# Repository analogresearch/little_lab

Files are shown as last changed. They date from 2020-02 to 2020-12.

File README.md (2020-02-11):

# LITTLE████_LAB

DC IN: 6..28 V 

MIDI noch noch nicht implementiert.

MIDI channel und Programm werden über Codierschalter gewählt.
MIDI: Ausnahme Schalter 0 = MIDI channel 16!

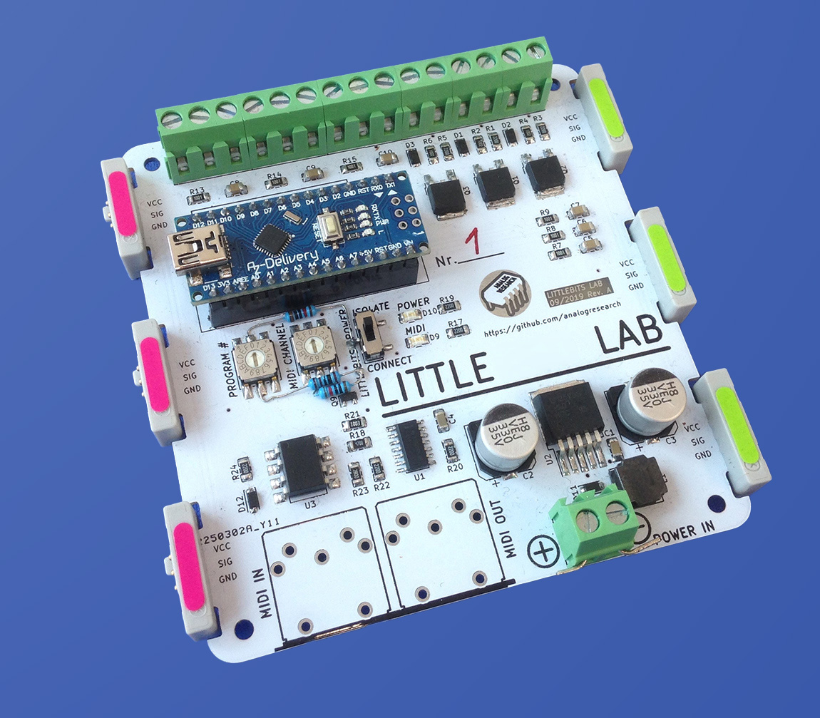
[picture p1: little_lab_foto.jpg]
ein Bild ein Foto


Rev.B: Pullups für Coderschalter
Rev.C: Pulldowns für inputs, debugging pads.

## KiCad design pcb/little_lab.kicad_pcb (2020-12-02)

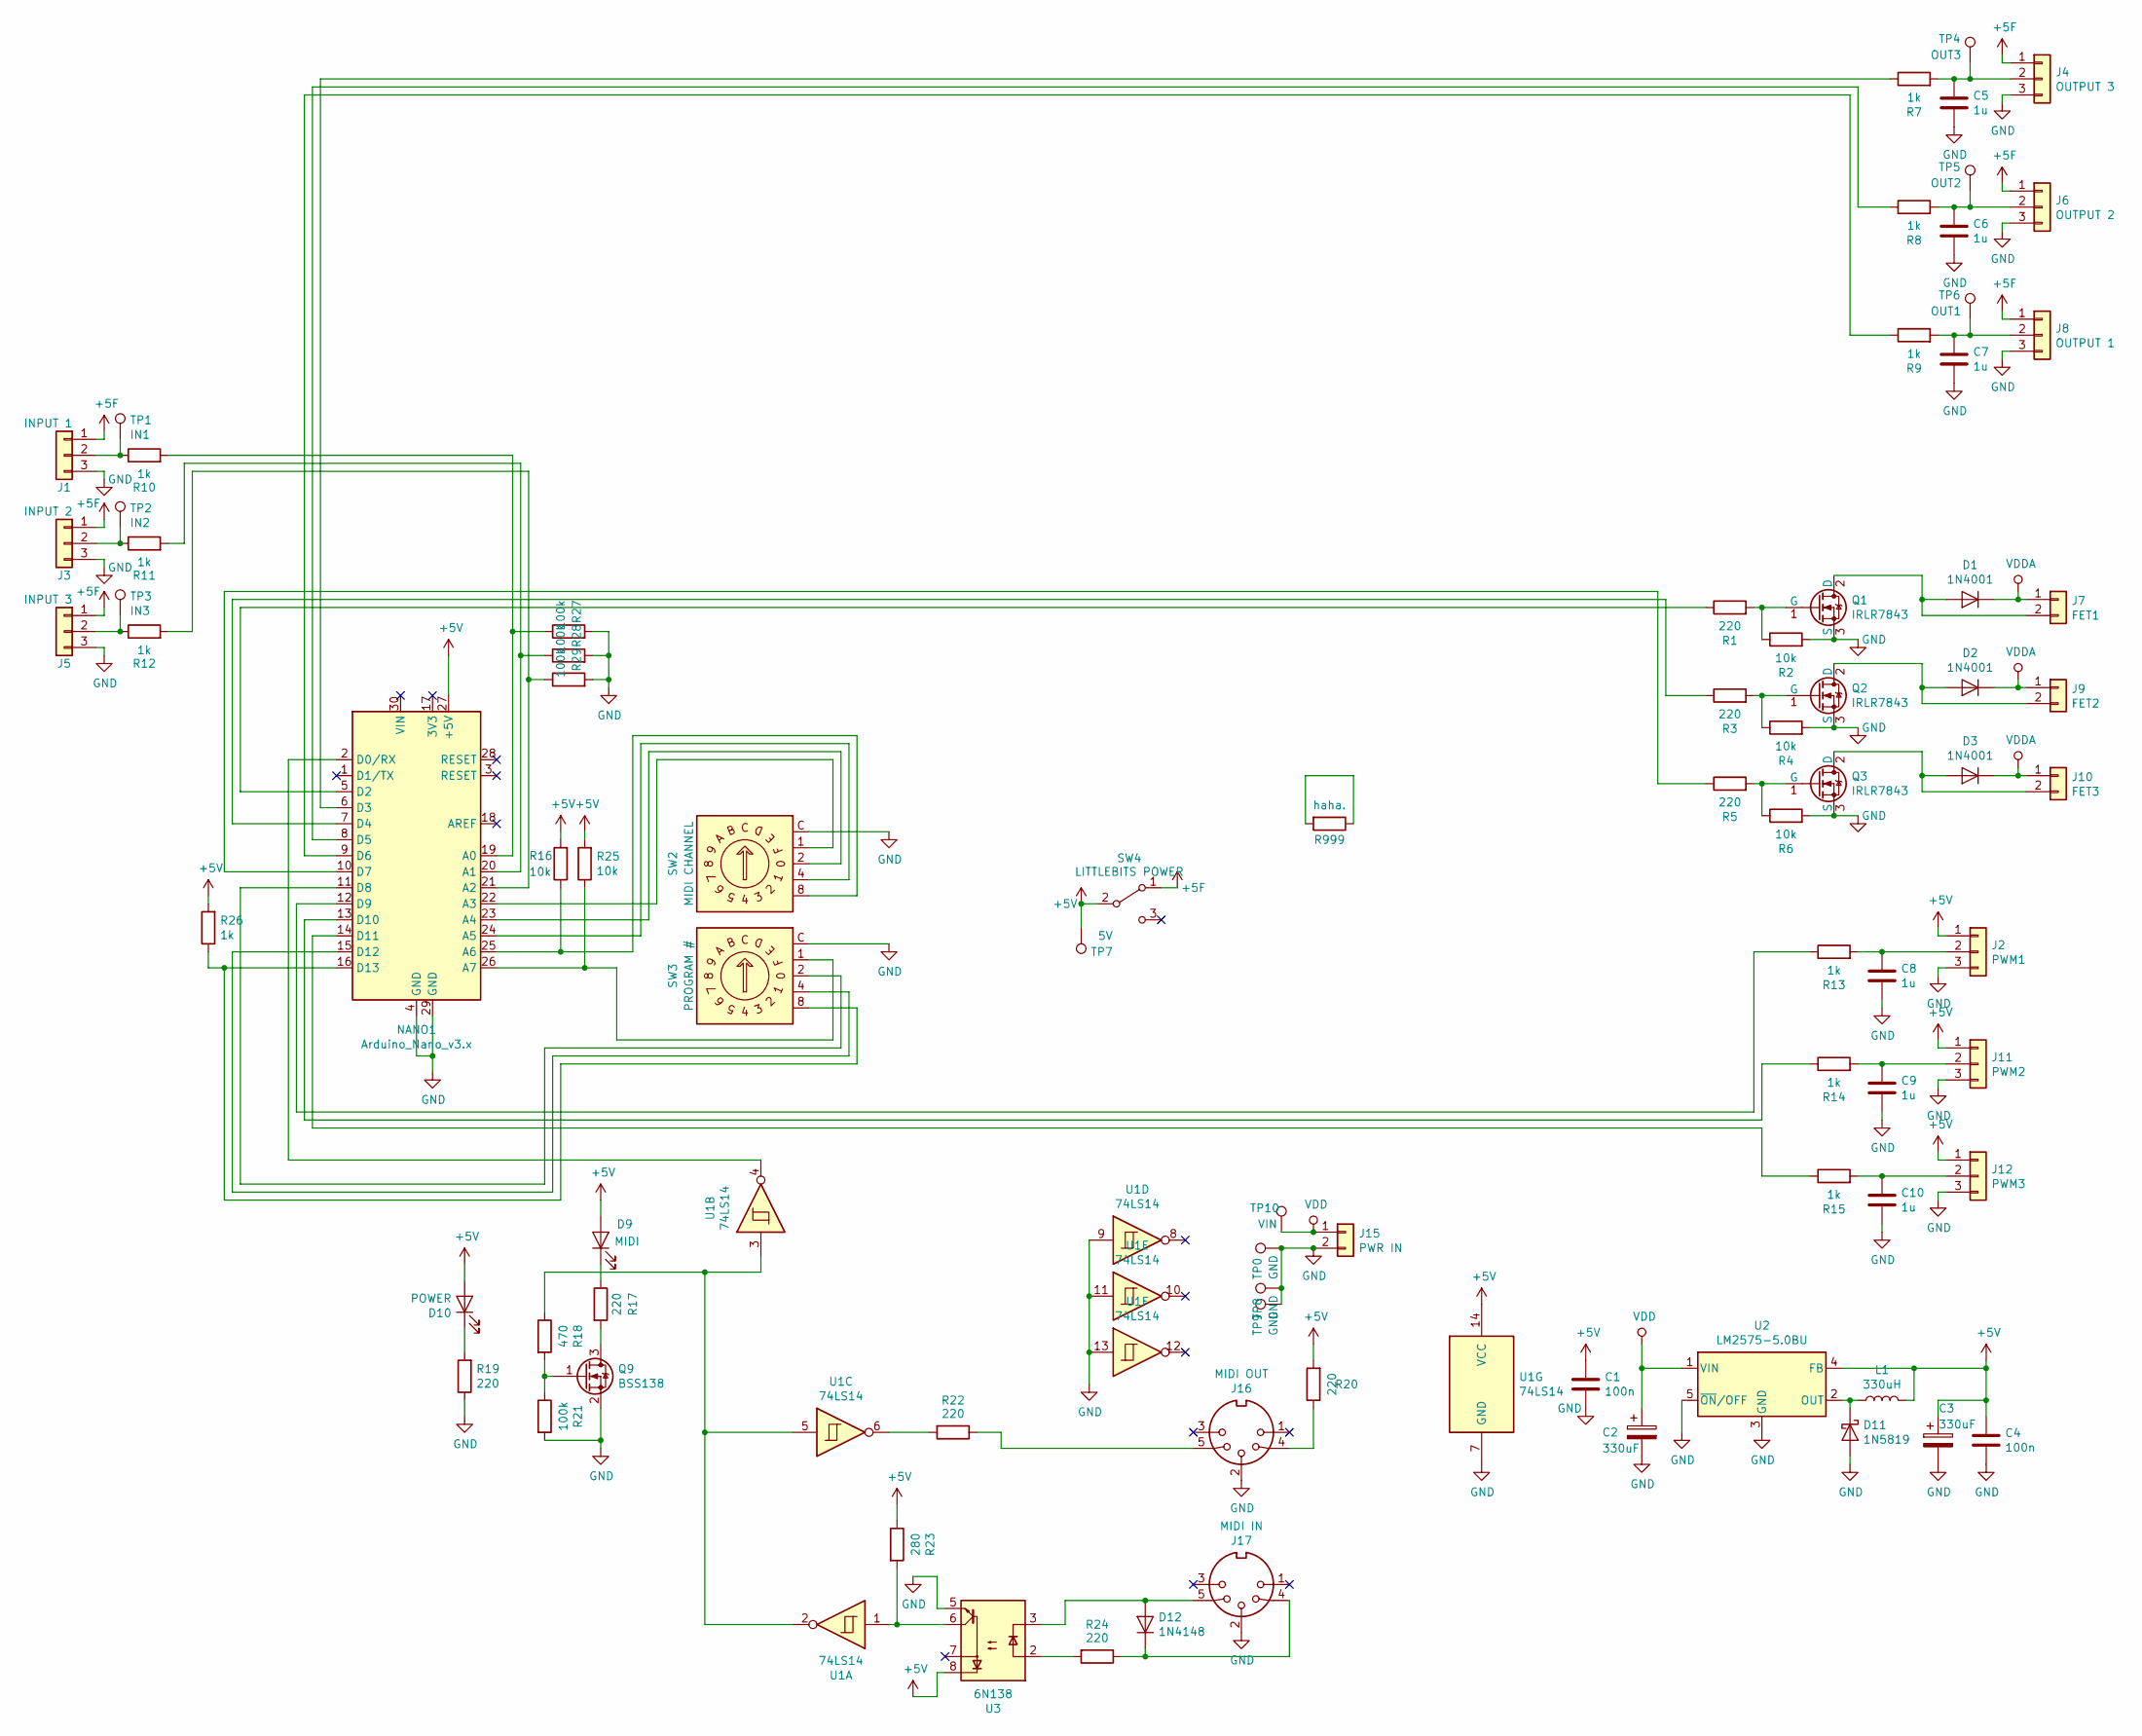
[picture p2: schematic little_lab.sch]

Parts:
C1, C4: 100n; C_1206_3216Metric_Pad1.42x1.75mm_HandSolder
C2, C3: 330uF; CP_Elec_10x10
C5, C6, C7, C8, C9, C10: 1u; C_1206_3216Metric_Pad1.42x1.75mm_HandSolder
D1, D2, D3: 1N4001; D_SOD-123F
D9: MIDI; LED_1206_3216Metric_Pad1.42x1.75mm_HandSolder
D10: POWER; LED_1206_3216Metric_Pad1.42x1.75mm_HandSolder
D11: 1N5819; D_SOD-123
D12: 1N4148; D_SOD-123
J1: INPUT 1; bitsnaps_input
J2: PWM1; EK508V-03P
J3: INPUT 2; bitsnaps_input
J4: OUTPUT 3; bitsnaps_output
J5: INPUT 3; bitsnaps_input
J6: OUTPUT 2; bitsnaps_output
J7: FET1; EK508V-02P
J8: OUTPUT 1; bitsnaps_output
J9: FET2; EK508V-02P
J10: FET3; EK508V-02P
J11: PWM2; EK508V-03P
J12: PWM3; EK508V-03P
J15: PWR IN; EK508V-02P
J16: MIDI OUT; MIDI_DIN5
J17: MIDI IN; MIDI_DIN5
L1: 330uH; L_7.3x7.3_Handsoldering
NANO1: Arduino_Nano_v3.x; Arduino_Nano
Q1, Q2, Q3: IRLR7843; TO-252-2
Q9: BSS138; SOT-23
R1, R3, R5, R17, R19, R20, R22, R24: 220; R_1206_3216Metric_Pad1.42x1.75mm_HandSolder
R2, R4, R6, R16, R25: 10k; R_1206_3216Metric_Pad1.42x1.75mm_HandSolder
R7, R8, R9, R10, R11, R12, R13, R14, R15, R26: 1k; R_1206_3216Metric_Pad1.42x1.75mm_HandSolder
R18: 470; R_1206_3216Metric_Pad1.42x1.75mm_HandSolder
R21, R27, R28, R29: 100k; R_1206_3216Metric_Pad1.42x1.75mm_HandSolder
R23: 280; R_1206_3216Metric_Pad1.42x1.75mm_HandSolder
R999: haha.; R_1206_3216Metric_Pad1.42x1.75mm_HandSolder
SW2: MIDI CHANNEL; SA-7050B
SW3: PROGRAM #; SA-7050B
SW4: LITTLEBITS POWER; K3-1235S-K1
TP0: GND; TestPoint_THTPad_D2.0mm_Drill1.0mm
TP1: IN1; TestPoint_THTPad_D2.0mm_Drill1.0mm
TP2: IN2; TestPoint_THTPad_D2.0mm_Drill1.0mm
TP3: IN3; TestPoint_THTPad_D2.0mm_Drill1.0mm
TP4: OUT3; TestPoint_THTPad_D2.0mm_Drill1.0mm
TP5: OUT2; TestPoint_THTPad_D2.0mm_Drill1.0mm
TP6: OUT1; TestPoint_THTPad_D2.0mm_Drill1.0mm
TP7: 5V; TestPoint_THTPad_D2.0mm_Drill1.0mm
TP8, TP9: GND; TestPoint_Pad_4.0x4.0mm
TP10: VIN; TestPoint_THTPad_D2.0mm_Drill1.0mm
U1: 74LS14; SOIC-14_3.9x8.7mm_P1.27mm
U2: LM2575-5.0BU; TO-263-5_TabPin3
U3: 6N138; SMDIP-8_W9.53mm

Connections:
+5F: J1.1, J3.1, J4.1, J5.1, J6.1, J8.1, SW4.1 (A)
+5V: C1.1, C3.1, C4.1, D9.2 (A), D10.2 (A), J2.1, J11.1, J12.1, L1.2, NANO1.27 (+5V), R16.2, R20.2, R23.1, R25.2, R26.2, SW4.2 (B), TP7.1, U1.14 (VCC), U2.4 (FB), U3.8
GND: C1.2, C2.2, C3.2, C4.2, C5.2, C6.2, C7.2, C8.2, C9.2, C10.2, D11.2 (A), J1.3, J2.3, J3.3, J4.3, J5.3, J6.3, J8.3, J11.3, J12.3, J15.2, J16.2, J17.2, NANO1.4 (GND), NANO1.29 (GND), Q1.3 (S), Q2.3 (S), Q3.3 (S), Q9.2 (S), R2.2, R4.2, R6.2, R19.1, R21.2, R27.2, R28.2, R29.2, SW2.C, SW3.C, TP0.1, TP8.1, TP9.1, U1.7 (GND), U1.9, U1.11, U1.13, U2.3 (GND), U2.5 (~ON~/OFF), U3.5
unnamed: C5.1, J4.2, R7.2, TP4.1
unnamed: C6.1, J6.2, R8.2, TP5.1
unnamed: C7.1, J8.2, R9.2, TP6.1
unnamed: C8.1, J2.2, R13.2
unnamed: C9.1, J11.2, R14.2
unnamed: C10.1, J12.2, R15.2
unnamed: D1.2 (A), J7.2, Q1.2 (D)
unnamed: D2.2 (A), J9.2, Q2.2 (D)
unnamed: D3.2 (A), J10.2, Q3.2 (D)
unnamed: D9.1 (K), R17.1
unnamed: D10.1 (K), R19.2
unnamed: D11.1 (K), L1.1, U2.2 (OUT)
unnamed: D12.1 (K), J17.4, R24.1
unnamed: D12.2 (A), J17.5, U3.3
unnamed: J1.2, R10.1, TP1.1
unnamed: J3.2, R11.1, TP2.1
unnamed: J5.2, R12.1, TP3.1
unnamed: J16.4, R20.1
unnamed: J16.5, R22.1
unnamed: NANO1.2 (D0/RX), U1.4
unnamed: NANO1.5 (D2), R1.1
unnamed: NANO1.6 (D3), R7.1
unnamed: NANO1.7 (D4), R3.1
unnamed: NANO1.8 (D5), R8.1
unnamed: NANO1.9 (D6), R9.1
unnamed: NANO1.10 (D7), R5.1
unnamed: NANO1.11 (D8), SW3.2
unnamed: NANO1.12 (D9), R13.1
unnamed: NANO1.13 (D10), R14.1
unnamed: NANO1.14 (D11), R15.1
unnamed: NANO1.15 (D12), SW3.4
unnamed: NANO1.16 (D13), R26.1, SW3.8
unnamed: NANO1.19 (A0), R10.2, R27.1
unnamed: NANO1.20 (A1), R11.2, R28.1
unnamed: NANO1.21 (A2), R12.2, R29.1
unnamed: NANO1.22 (A3), SW2.1
unnamed: NANO1.23 (A4), SW2.2
unnamed: NANO1.24 (A5), SW2.4
unnamed: NANO1.25 (A6), R16.1, SW2.8
unnamed: NANO1.26 (A7), R25.1, SW3.1
unnamed: Q1.1 (G), R1.2, R2.1
unnamed: Q2.1 (G), R3.2, R4.1
unnamed: Q3.1 (G), R5.2, R6.1
unnamed: Q9.1 (G), R18.2, R21.1
unnamed: Q9.3 (D), R17.2
unnamed: R18.1, U1.2, U1.3, U1.5
unnamed: R22.2, U1.6
unnamed: R23.2, U1.1, U3.6
unnamed: R24.2, U3.2
unnamed: R999.1, R999.2
VDD: C2.1, J15.1, TP10.1, U2.1 (VIN)
VDDA: D1.1 (K), D2.1 (K), D3.1 (K), J7.1, J9.1, J10.1

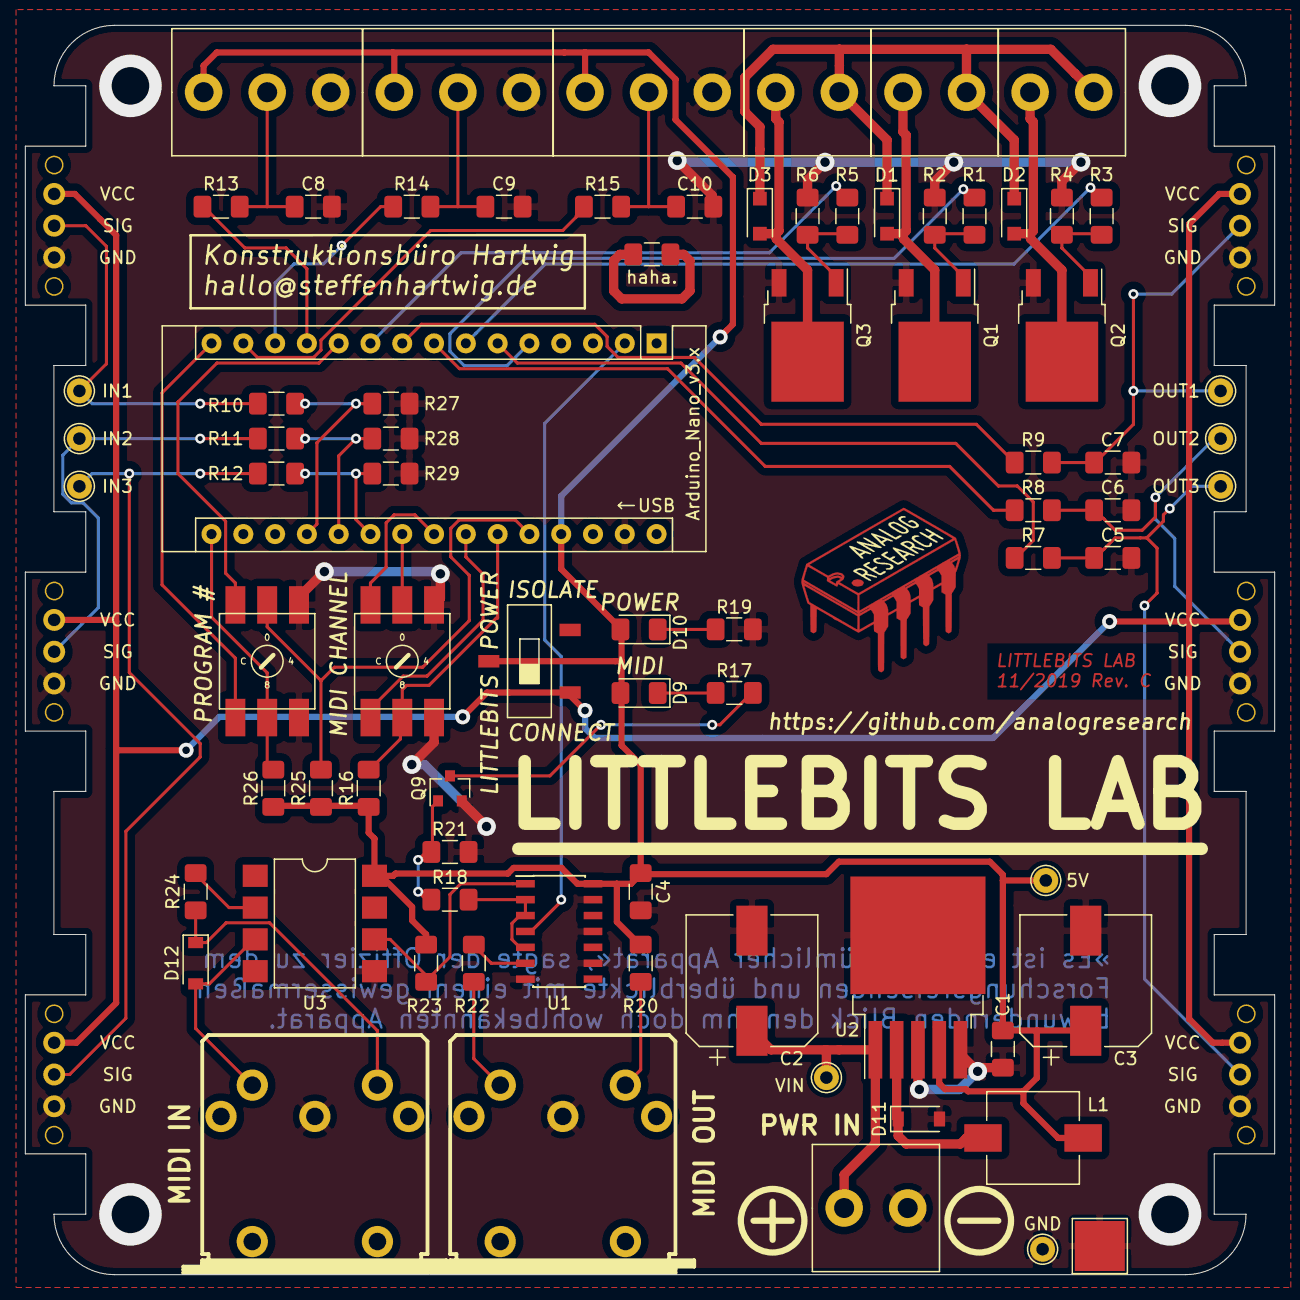
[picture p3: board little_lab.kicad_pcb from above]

Board: 2 copper layers, 99.8 x 99.8 mm, 86 parts (1 on the bottom side), 55 nets.

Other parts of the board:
Ref**: Val**; logo-analogresearch-16mm

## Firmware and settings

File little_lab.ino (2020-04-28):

//////////////////////
/// LITTLE████_LAB ///
//////////////////////
/// version 0.2 //////
//////////////////////
/// stef ♥ 2020 //////
//////////////////////

byte midi_channel;
byte program;

int in1, in2, in3;
int out1, out2, out3;

void setup() {
  Serial.begin(19200);

  setPwmFrequency(5, 8);
  setPwmFrequency(6, 8);
  setPwmFrequency(3, 8);

  //lb inputs
  pinMode(A0, INPUT); //in1
  pinMode(A1, INPUT); //in2
  pinMode(A2, INPUT); //in3

  //lb outputs
  pinMode(6, OUTPUT); //out1
  pinMode(5, OUTPUT); //out2
  pinMode(3, OUTPUT); //out3

  //schalter für midi channel
  pinMode(A3, INPUT_PULLUP); //1
  pinMode(A4, INPUT_PULLUP); //2
  pinMode(A5, INPUT_PULLUP); //4
  pinMode(A6, INPUT_PULLUP); //8

  //schalter für program nr
  pinMode(A7, INPUT_PULLUP); //1
  pinMode(8, INPUT_PULLUP);  //2
  pinMode(12, INPUT_PULLUP); //4
  pinMode(13, INPUT_PULLUP); //8

  set_address();
  set_program();
}

void loop() {
  set_address();
  set_program();
  Serial.print("m:\t");
  Serial.print(midi_channel);
  Serial.print("\tp:\t");
  Serial.print(program);

  switch (program) {
    case 1:
      //testprogramm 1

      in1 = analogRead(A0);
      in2 = analogRead(A1);
      in3 = analogRead(A2);

      out1 = in1 / 4;
      out2 = in2 / 4;
      out3 = in3 / 4;

      analogWrite(6, out1);
      analogWrite(5, out2);
      analogWrite(3, out3);

      Serial.print("\tin:\t");
      Serial.print(in1);
      Serial.print("\t");
      Serial.print(in2);
      Serial.print("\t");
      Serial.print(in3);

      Serial.print("\tout:\t");
      Serial.print(out1);
      Serial.print("\t");
      Serial.print(out2);
      Serial.print("\t");
      Serial.println(out3);

      delay(100);
      break;
    case 2:
      //testprogramm 2
      //do nothing
      break;
    default:
      //do nothing
      break;
  }
}

void set_address() { // midi codeswitch auslesen
  midi_channel = !digitalRead(A3) + (!digitalRead(A4) << 1) + (!digitalRead(A5) << 2 ) + (!(analogRead(A6) > 512) << 3);
  if (midi_channel == 0) midi_channel = 16;
}

void set_program() { // program codeswitch auslesen
  program = !(analogRead(A7) > 512) + (!digitalRead(8) << 1) + (!digitalRead(12) << 2 ) + (!digitalRead(13) << 3);
}

void setPwmFrequency(int pin, int divisor) {
  byte mode;
  if (pin == 5 || pin == 6 || pin == 9 || pin == 10) {
    switch (divisor) {
      case 1: mode = 0x01; break;
      case 8: mode = 0x02; break;
      case 64: mode = 0x03; break;
      case 256: mode = 0x04; break;
      case 1024: mode = 0x05; break;
      default: return;
    }
    if (pin == 5 || pin == 6) {
      TCCR0B = TCCR0B & 0b11111000 | mode;
    } else {
      TCCR1B = TCCR1B & 0b11111000 | mode;
    }
  } else if (pin == 3 || pin == 11) {
    switch (divisor) {
      case 1: mode = 0x01; break;
      case 8: mode = 0x02; break;
      case 32: mode = 0x03; break;
      case 64: mode = 0x04; break;
      case 128: mode = 0x05; break;
      case 256: mode = 0x06; break;
      case 1024: mode = 0x07; break;
      default: return;
    }
    TCCR2B = TCCR2B & 0b11111000 | mode;
  }
}
